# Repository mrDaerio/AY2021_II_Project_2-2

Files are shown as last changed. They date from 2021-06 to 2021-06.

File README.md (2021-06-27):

# Project 2 - Heart Rate Monitor Accelerometer
This repository contains all the files used to build a heart rate monitoring device, as requested by the final project of the course. The hardware used for this project consists in the CY8CKIT-059, a HC-05 Bluetooth module, a LIS3DH accelerometer and a breadbord which allows to connect all the components.

In this file are listed all the steps to reproduce and program the device, with also explanatory photos and images to help the user in the process.

## Device Building and Placement
In this first section is explained in detail how to build the device and where to place it on the body in order to obtain the best signal acquisition.

### Material:

As illustrated in the picture below, in order to reproduce the device is needed a microcontroller, a bluetooth module, an accelerometer (with the 3D printed case) and an elastic band to easily place it on the torax. The powerbank is not mandatory, but it is useful if the subject wants to have the possiblity to be physically detached from the computer.

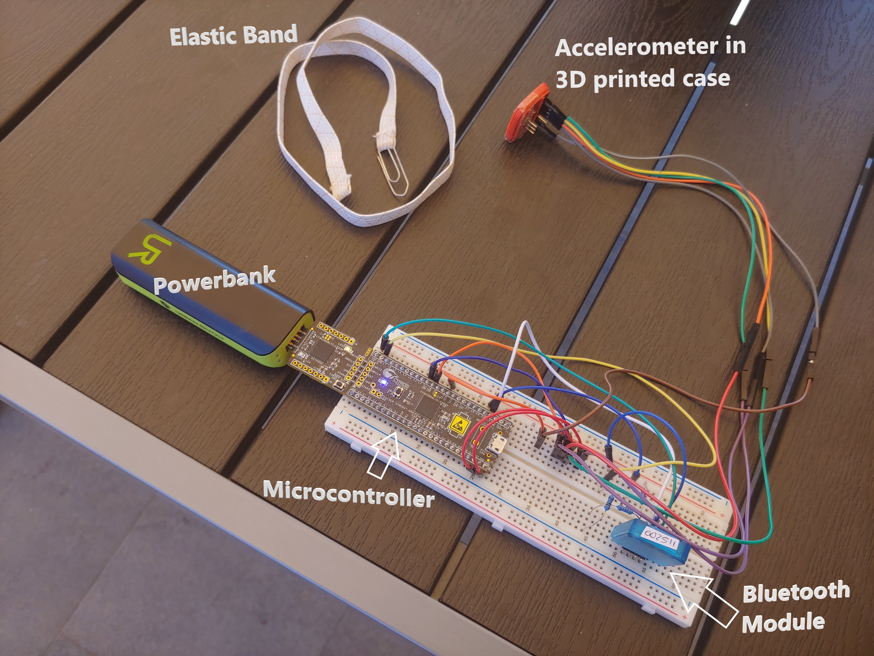
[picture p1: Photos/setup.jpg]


### Connection:

Follow the table below to properly connect the pins of the components to the microcontroller:

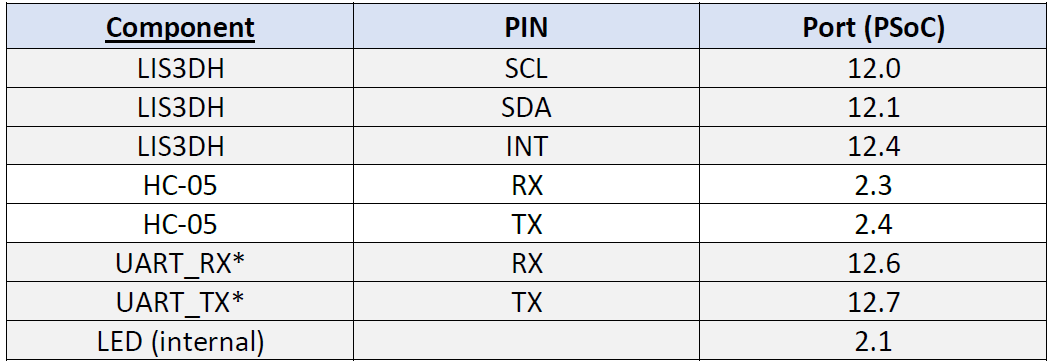
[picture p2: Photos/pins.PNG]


### 3D Case:

In order to have a better adeherence of the accelerometer to the body, and a better support for the elastic band, a special case has been developed, and it is possible to find all the relative information in the folder named "Case". 
The relative README file in the folder explains how to attach the case to the accelerometer.

### How to wear the sensor:

The rubber band needs to be placed behind the case, like showed in the picture below. 



A 3D animation shows how the accelerometer needs to be placed on the body, in order to obtain good acquisitions.



## Programming the Microcontroller

Once the repository has been downloaded on the computer, it's possible to program the kit through PSoC creator. To do that, simply double click on the file "Workspace01.cywrk",  and PSoC Creator will automatically open. Compile the project and upload it on the board. In the Top Design file is also possible to find other information and visual representation on how to connect the components to the board, if not clear.
Mind that a specific library has been used, called AnnotationLibrary. You might have to add it in order to correctly build the project and program the device.

If all the connection are correct, at the end of the programming phase you should have a red led blinking on the bluetooth module and the blue led of the microcontroller lighted up. If the blue led is blinking, it means that the accelerometer is not connected properly.

## GUI

The GUI has been developed with kivy, and allows to display the data retrieved by the microcontroller and elaborate them to extract the heart rate of the subject. Through the interface is possible also to have a graphical representation of the signal rielaborated, in order to have a clear representation of the beating, and also allows to change internal parameter of the microcontroller, such as the sample rate and the full scale range. Another feature is the data export of the three raw channels of the accelerometers in a .csv file, which can be used for further studies or further data elaboration on other platforms.
The microcontroller is also able to save the last parameter that the user has set, and retrieve them for the next session.

All the packets that need to be installed in the virtual environment to make the interface work are listed in the folder named "GUI". The bluetooth module connection with the computer can be established in the bluetooth settings, as any other bluetooth device. The module is called "HC-05", but the name may differ.

### First Run

Run the "main.py" file from a Python virtual environment to start the GUI. This window should appear:

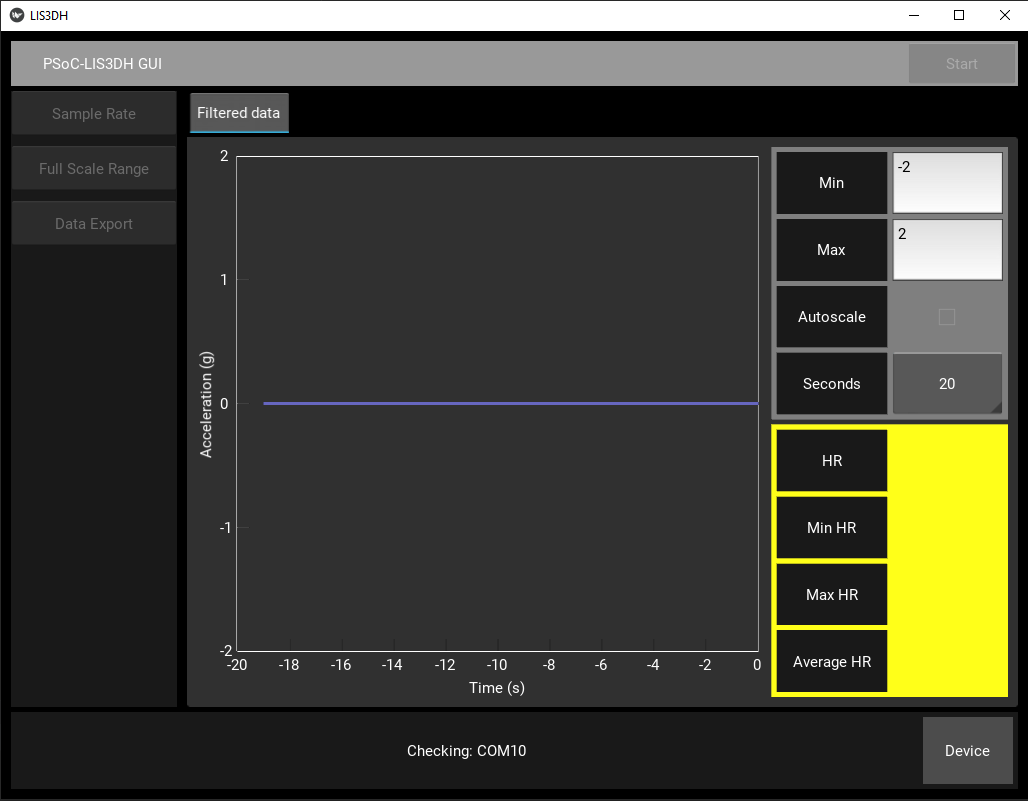
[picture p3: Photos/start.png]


### Connection

Once the connection with the bluetooth module has been established, the graphical interface should look like this:

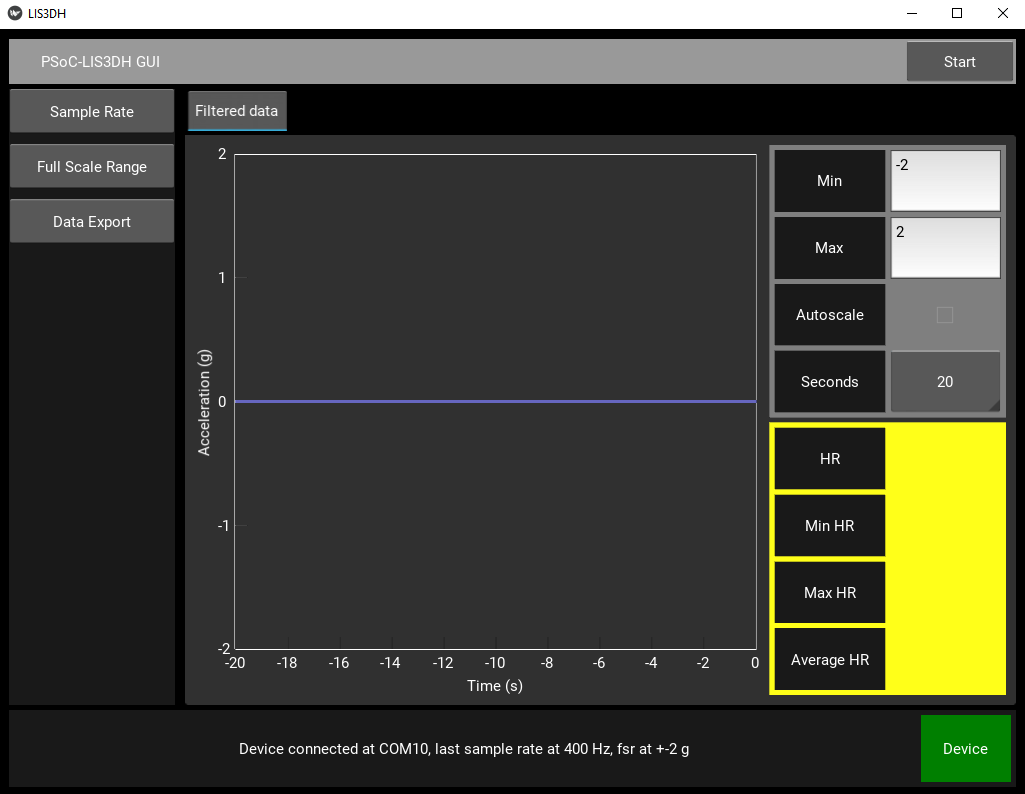
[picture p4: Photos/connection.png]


As it is possible to notice, the selection buttons can now be pressed to change the parameters of the microcontroller, and start button on the top right corner enables the data streaming and the graphical representation of the data.

The GUI should visualize the signal in this way:

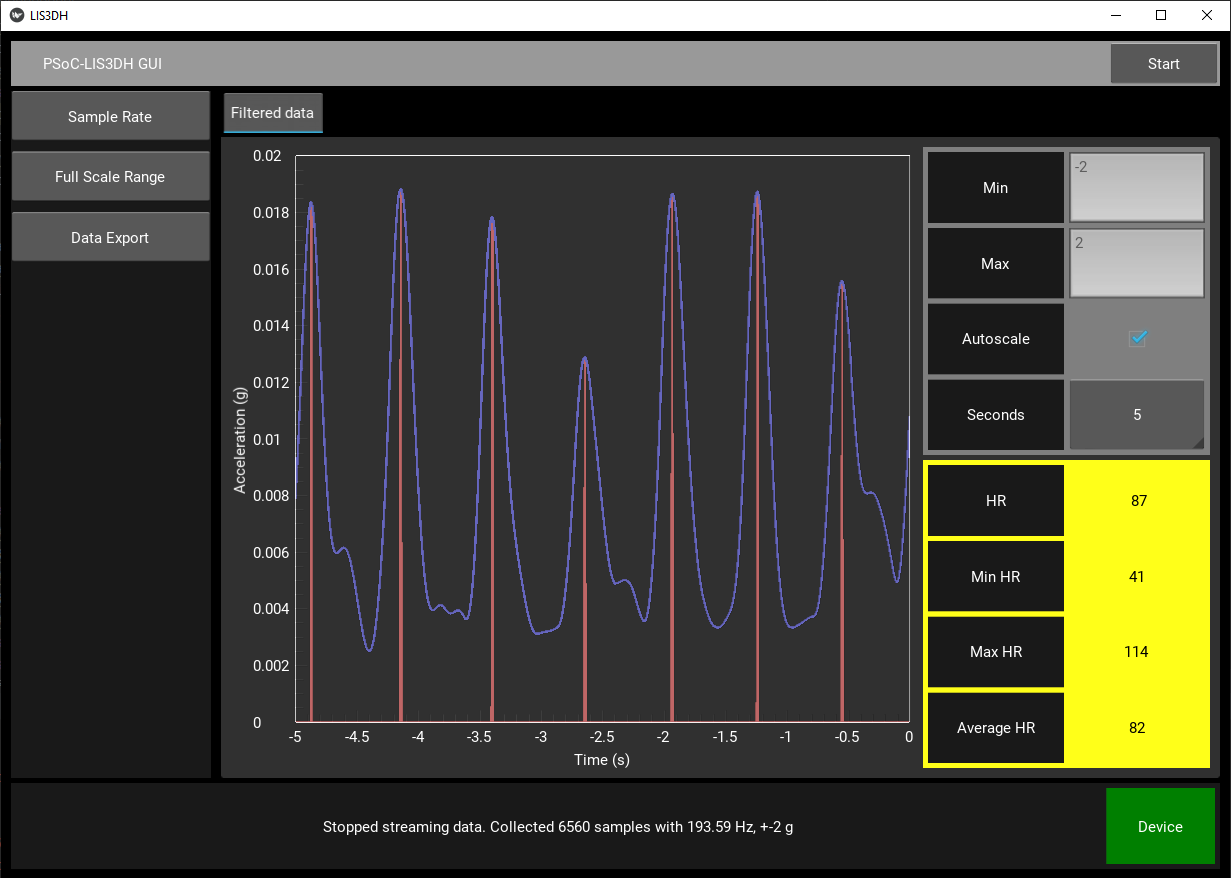
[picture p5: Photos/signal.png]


To interrput the connection, simply press the stop button. The data export button allows to save the current session locally in the computer.

Note that you have to wait about 10 seconds before seeing any plot on the GUI because vectors need to be filled and data needs to be processed.

The exported data saved in the csv file will contain all the data of the last acquisition (time between start and stop commands).

### How is the GUI structured?

Since the GUI code can be complicated at first glance, this graph tries to simplify and clarify every connection inside the code.
[Map of the GUI](https://miro.com/app/board/o9J_lDBEVHY=/)

## Students Authors of the Project

* Dario Comini

* Stefano Lucchesini

* Giovanni Merighi

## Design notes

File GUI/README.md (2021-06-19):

# LIS3DH GUI
This is a GUI showing how to read, parse, and plot acceleration data from a LIS3DH accelerometer.

## Requirements
- Kivy
- Kivy-Garden graph. To install it, run this command inside your virtual environment:
    - garden install graph
- PySerial
- SciPy
- numpy
- scikit-learn
- pandas

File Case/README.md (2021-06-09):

# Readme - HR monitor 3D Case
This folder contains the necessary files to 3D print a case for the LIS3DH accelerometer.
* The top part of the case ("Tappo") has two holes to let headers and wiring pass through <br/> and two small walls which are used to keep an elastic band in position.
* The bottom part ("Base") goes in contact with the skin and has two plastic pillars to keep the accelerometer board fixed.\
Base and Tappo can be glued together after the board is put inside.
* The .STEP file contains the 3D model, it can be opened in any 3D CAD app, we used FUSION 360.

| | |
|-|-|
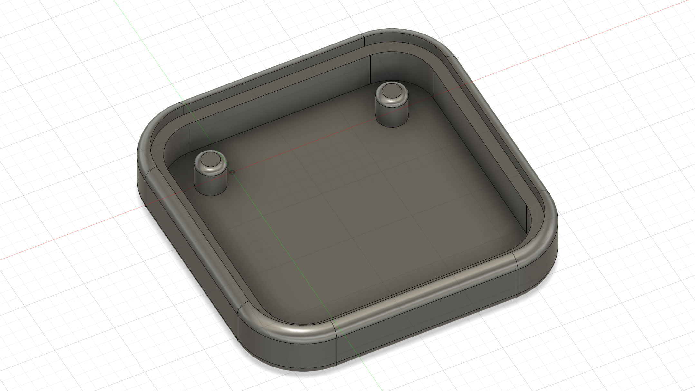
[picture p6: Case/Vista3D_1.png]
Vista_3D_1
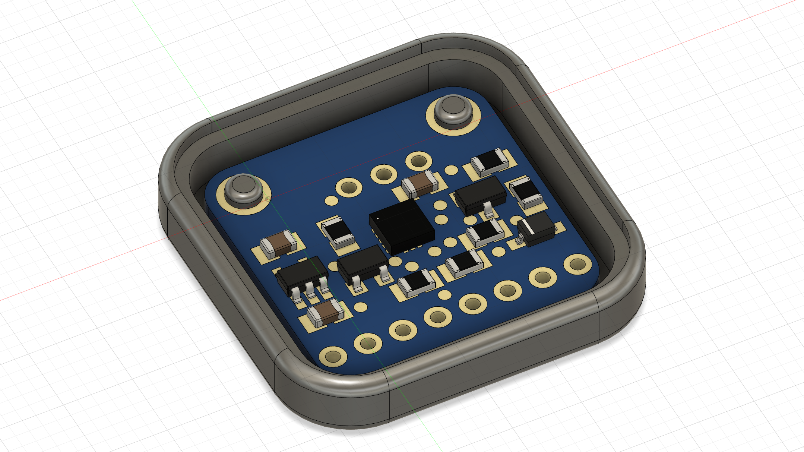
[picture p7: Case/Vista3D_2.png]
Vista_3D_2
|   |   |
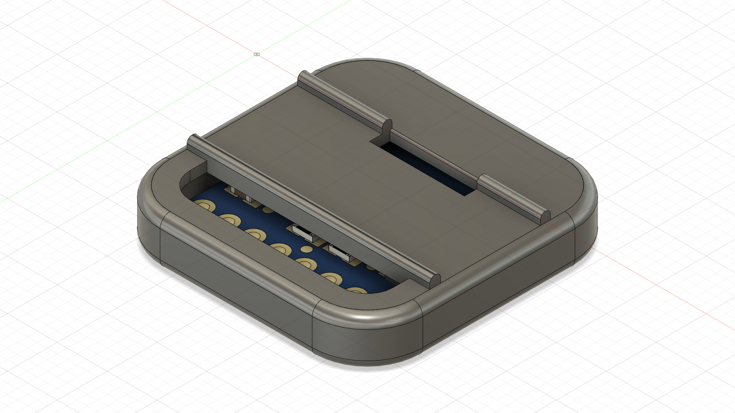
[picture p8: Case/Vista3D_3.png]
Vista_3D_3
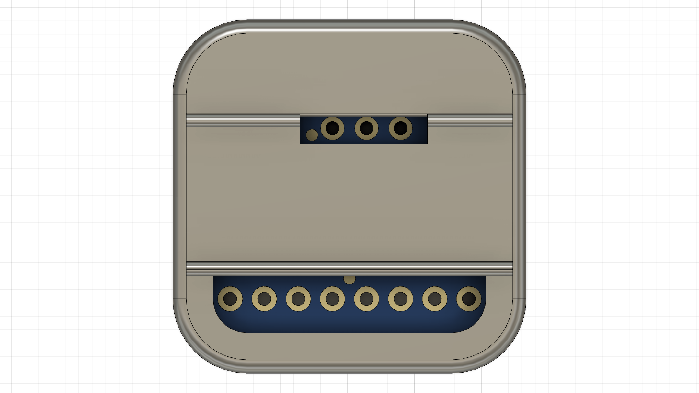
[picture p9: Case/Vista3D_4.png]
Vista_3D_4
|   |   |

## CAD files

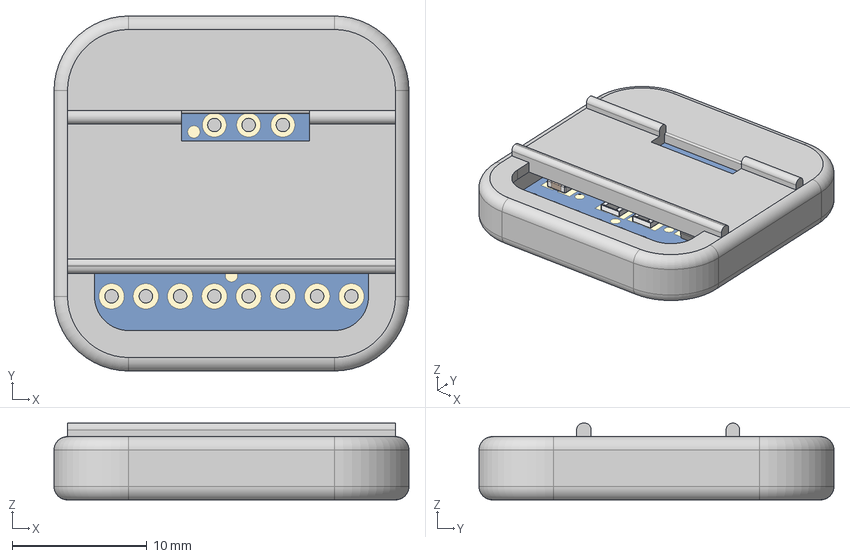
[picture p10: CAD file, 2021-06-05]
Case/HR Monitor Case.step
26.3 x 26.3 x 5.70 mm
SOT23-5 v1
SOT23-3 v1 x 2
16-LGA-3X3 v2
SMD Resistor 0805 v1 x 6
Cap 0805 v1 x 3
SOD-323 v1

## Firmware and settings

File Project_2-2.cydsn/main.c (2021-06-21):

/* =============================================================================
 
    Electronic Technologies and Biosensors Laboratory
    Academic Year 2020/2021 - II Semester
    Final Project
    GROUP_02 - Variant 2

    main.c: source file
 
 * =============================================================================
*/

#include "project.h"
#include "stdio.h"
#include "I2C_Interface.h"
#include "LIS3DH.h"
#include "ErrorCodes.h"
#include "InterruptRoutines.h"

// Definition of led value for blinking
#define LED_ON 99
#define LED_BLINK 50

// Definition of head and tail for data packets
#define HEAD 0xA0
#define TAIL 0xC0

// Definition of buffer size
#define BUFFER_SIZE 194

uint8_t flag = 0;
int16_t x_buffer[FIFO_SIZE], y_buffer[FIFO_SIZE], z_buffer[FIFO_SIZE];
uint8_t buffer[BUFFER_SIZE];

int main(void)
{
    CyGlobalIntEnable; /* Enable global interrupts. */
    
    // Start all components
    I2C_Peripheral_Start();
    UART_DEBUG_Start();
    UART_BT_Start();
    isr_FIFO_StartEx(Custom_ISR_FIFO);
    isr_BT_StartEx(Custom_ISR_RXBT);
    PWM_LED_Start();
    
    CyDelay(5); //"The boot procedure is complete about 5 ms after device power-up."
    
    if (!I2C_Peripheral_IsDeviceConnected(LIS3DH_DEVICE_ADDRESS))
        PWM_LED_WriteCompare(LED_BLINK);
    else
        PWM_LED_WriteCompare(LED_ON);
        
    CyDelay(10);
        
    // Accelerometer powered down
    ErrorCode error = set_datarate(LIS3DH_DATARATE_POWERDOWN);
    error_check(error);
    
    // Enables FIFO
    error = FIFO_set(1, FIFO_MODE);
    error_check(error);

    buffer[0] = HEAD;
    buffer[BUFFER_SIZE-1] = TAIL;
    
    for(;;)
    {      
        if(flag){
            flag = 0;
            for(int i=1; i <= FIFO_SIZE; i++) {
                    buffer[2*i - 1] = x_buffer[i-1] >> 8;
                    buffer[2*i] = x_buffer[i-1];
                    buffer[2*i + 2*FIFO_SIZE - 1] = y_buffer[i-1] >> 8;
                    buffer[2*i + 2*FIFO_SIZE] = y_buffer[i-1];
                    buffer[2*(i + 2*FIFO_SIZE) - 1] = z_buffer[i-1] >> 8;
                    buffer[2*(i + 2*FIFO_SIZE)] = z_buffer[i-1];
            }
            UART_BT_PutArray(buffer, BUFFER_SIZE);
        }    
    }
}

/* [] END OF FILE */

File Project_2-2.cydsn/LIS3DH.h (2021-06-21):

/* =============================================================================
 
    Electronic Technologies and Biosensors Laboratory
    Academic Year 2020/2021 - II Semester
    Final Project
    GROUP_02 - Variant 2

    LIS3DH.h: header file 

    This is a library for the Adafruit LIS3DH Accel breakout board
    Designed specifically to work with the Adafruit LIS3DH Triple-Axis
    Accelerometer
    (+-2g/4g/8g/16g)
    This sensor communicates over I2C or SPI (our library code supports
    both) so you can share it with a bunch of other sensors on the same I2C bus.
    There's an address selection pin so you can have two accelerometers share an
    I2C bus.
    
    Adafruit invests time and resources providing this open source code,
    please support Adafruit andopen-source hardware by purchasing products
    from Adafruit!
 
 * =============================================================================
*/

#include "cytypes.h"
#include "ErrorCodes.h"
#include "I2C_Interface.h"

#ifndef __LIS3DH_H
    #define __LIS3DH_H
    
    // Definition of the size of the FIFO
    #define FIFO_SIZE 32
    
    /** I2C ADDRESS/BITS **/
    #define LIS3DH_DEVICE_ADDRESS (0x18) // if SDO/SA0 is 3V, its 0x19

    /*!
     *  STATUS_REG_AUX register
     *   321OR  1, 2 and 3 axis data overrun. Default value: 0
     *          (0: no overrun has occurred; 1: a new set of data has overwritten
     *  the previous ones) 3OR    3 axis data overrun. Default value: 0 (0: no
     *  overrun has occurred; 1: a new data for the 3-axis has overwritten the
     *  previous one) 2OR    2 axis data overrun. Default value: 0 (0: no overrun has
     *  occurred; 1: a new data for the 4-axis has overwritten the previous one) 1OR
     *  1 axis data overrun. Default value: 0 (0: no overrun has occurred; 1: a new
     *  data for the 1-axis has overwritten the previous one) 321DA  1, 2 and 3 axis
     *  new data available. Default value: 0 (0: a new set of data is not yet
     *  available; 1: a new set of data is available) 3DA:   3 axis new data
     *  available. Default value: 0 (0: a new data for the 3-axis is not yet
     *  available; 1: a new data for the 3-axis is available) 2DA:   2 axis new data
     *  available. Default value: 0 (0: a new data for the 2-axis is not yet
     *  available; 1: a new data for the 2-axis is available) 1DA    1 axis new data
     *  available. Default value: 0 (0: a new data for the 1-axis is not yet
     *  available; 1: a new data for the 1-axis is available)
     */
    #define LIS3DH_REG_STATUS1 0x07
    
    #define LIS3DH_REG_OUTADC1_L 0x08 /**< 1-axis acceleration data. Low value */
    #define LIS3DH_REG_OUTADC1_H 0x09 /**< 1-axis acceleration data. High value */
    #define LIS3DH_REG_OUTADC2_L 0x0A /**< 2-axis acceleration data. Low value */
    #define LIS3DH_REG_OUTADC2_H 0x0B /**< 2-axis acceleration data. High value */
    #define LIS3DH_REG_OUTADC3_L 0x0C /**< 3-axis acceleration data. Low value */
    #define LIS3DH_REG_OUTADC3_H 0x0D /**< 3-axis acceleration data. High value */
    
    #define LIS3DH_REG_INTCOUNT                                                    \
      0x0E /**< INT_COUNTER register [IC7, IC6, IC5, IC4, IC3, IC2, IC1, IC0] */
    
    #define LIS3DH_REG_WHOAMI                                                      \
      0x0F /**< Device identification register. [0, 0, 1, 1, 0, 0, 1, 1] */
    #define LIS3DH_WHOAMI_RETVAL 0x33  // WHO AM I register return value
    
    #define LIS3DH_NORMAL_MODE_OFF_CTRL_REG1 0x07  // Hex value to set normal mode (powered off)
    
    /*!
     *  TEMP_CFG_REG
     *  Temperature configuration register.
     *   ADC_PD   ADC enable. Default value: 0
     *            (0: ADC disabled; 1: ADC enabled)
     *   TEMP_EN  Temperature sensor (T) enable. Default value: 0
     *            (0: T disabled; 1: T enabled)
     */
    #define LIS3DH_REG_TEMPCFG 0x1F
    
    #define LIS3DH_TEMP_CFG_REG_ACTIVE 0xC0
    
    #define LIS3DH_CTRL_REG0 0x1E
    
    /*!
     *  CTRL_REG1
     *  [ODR3, ODR2, ODR1, ODR0, LPen, Zen, Yen, Xen]
     *   ODR3-0  Data rate selection. Default value: 00
     *           (0000:50 Hz; Others: Refer to Datasheet Table 26, “Data rate
     * configuration”) LPen    Low power mode enable. Default value: 0 (0: normal
     * mode, 1: low power mode) Zen     Z axis enable. Default value: 1 (0: Z axis
     * disabled; 1: Z axis enabled) Yen     Y axis enable. Default value: 1 (0: Y
     * axis disabled; 1: Y axis enabled) Xen     X axis enable. Default value: 1 (0:
     * X axis disabled; 1: X axis enabled)
     */
    #define LIS3DH_REG_CTRL1 0x20
    
    /*!
     *  CTRL_REG2
     *  [HPM1, HPM0, HPCF2, HPCF1, FDS, HPCLICK, HPIS2, HPIS1]
     *   HPM1-0  High pass filter mode selection. Default value: 00
     *           Refer to Table 29, "High pass filter mode configuration"
     *   HPCF2-1 High pass filter cut off frequency selection
     *   FDS     Filtered data selection. Default value: 0
     *					 (0: internal filter bypassed; 1: data
     *from internal filter sent to output register and FIFO) HPCLICK High pass
     *filter enabled for CLICK function. (0: filter bypassed; 1: filter enabled)
     *HPIS2   X axis enable. Default value: 1 (0: X axis disabled; 1: X axis
     *enabled) HPIS1 High pass filter enabled for AOI function on interrupt 1, (0:
     *filter bypassed; 1: filter enabled)
     */
    
    #define LIS3DH_REG_CTRL1_DATA_RATE_BITS_MASK 0b11110000
    #define LIS3DH_REG_CTRL1_RANGE_BITS_MASK 0b00110000
    #define LIS3DH_REG_CTRL5_FIFO_SET_BITS_MASK 0b01000000
    #define LIS3DH_REG_FIFOCTRL_FIFO_MODE_BITS_MASK 0b11000000
    #define LIS3DH_REG_CTRL3_FIFO_INT1_BITS_MASK 0b00000010
    
    
    
    #define LIS3DH_REG_CTRL2 0x21
    
    /*!
     *  CTRL_REG3
     *  [I1_CLICK, I1_AOI1, I1_AOI2, I1_DRDY1, I1_DRDY2, I1_WTM, I1_OVERRUN, --]
     *   I1_CLICK    CLICK interrupt on INT1. Default value 0.
     *						   (0: Disable; 1: Enable)
     *   I1_AOI1     AOI1 interrupt on INT1. Default value 0.
     *						   (0: Disable; 1: Enable)
     *   I1_AOI2     AOI2 interrupt on INT1. Default value 0.
     *               (0: Disable; 1: Enable)
     *   I1_DRDY1    DRDY1 interrupt on INT1. Default value 0.
     *               (0: Disable; 1: Enable)
     *   I1_DRDY2    DRDY2 interrupt on INT1. Default value 0.
     *               (0: Disable; 1: Enable)
     *   I1_WTM      FIFO Watermark interrupt on INT1. Default value 0.
     *               (0: Disable; 1: Enable)
     *   I1_OVERRUN  FIFO Overrun interrupt on INT1. Default value 0.
     * 							 (0: Disable; 1: Enable)
     */
    #define LIS3DH_REG_CTRL3 0x22
    
    /*!
     *  CTRL_REG4
     *  [BDU, BLE, FS1, FS0, HR, ST1, ST0, SIM]
     *   BDU      Block data update. Default value: 0
     *            (0: continuos update; 1: output registers not updated until MSB
     * and LSB reading) BLE      Big/little endian data selection. Default value 0.
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

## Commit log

2021-05-07 successfully read accelerometer X-axis LSB
2021-05-07 LSB and MSB read x-axis
2021-05-08 Error handling and functions to read and write registers
    [ErrorCodes.c, LIS3DH.h, main.c]
2021-05-08 Added datarate set function, FIFO set function, readout of all axes. Interrupt pin in topdesign
2021-05-09 Every function has its own error code, useful to quickly see (via UART) if there's any problem with the code
    [ErrorCodes.c, I2C_Interface.c, main.c]
2021-05-10 FIFO read with interrupt handling
2021-05-10 LED handling and macros for CTRL_REG bits
2021-05-11 simplified functions with set_reg_masked_only, macros for LED state, corrected ';' in some macros
    [LIS3DH.h, main.c]
2021-05-15 Added 400Hz and 1344Hz in gui
2021-05-15 Modified the variation in the interrupt of the sample rate, but the GUI doesn't work the after the second change
2021-05-17 Renamed values to avoid hard coding
    [main.c]
2021-05-17 Corrected typo in buffer handling
    [main.c]
2021-05-22 Band pass filtering of z+x signal using SciPy and plot in GUI in place of y
2021-05-22 sliding window for filter, first attempt for envelope
2021-05-26 Corrected sample_rate and used it for bpm calculation
    [communication.py]
2021-05-29 Removed frequencies below 100Hz, set 200Hz as default, disabled range select button
2021-05-29 Added filtered graph tab, only one tab working at a time because of high latency, corrected autoscale problem
    [communication.py, graph_tabs.py]
2021-06-02 FIFO read using ReadRegisterMulti function, sample rate now goes closer to the target one
2021-06-05 Added 3D case files
    [HR Monitor Case.step]
2021-06-05 Added miracolous fix with lowpass filter and corrected y_min autoscale
    [communication.py, graph_tabs.py]
2021-06-09 3D case images in README.md
2021-06-15 code organization in filtering part
2021-06-15 adaptive filtering of envelope, relative prominence, simplified logic peaks
2021-06-15 added min and max bpm visualization, prevented autoscale to cut the top of peaks
    [graph_tabs.py]
2021-06-19 Disable the GUI in case of I2C error, shorter window size
    [communication.py, main.py]
2021-06-19 Enter in an infinite loop and send error message in case o I2C disconnection
    [ErrorCodes.c, I2C_Interface.c, main.c]
2021-06-21 Removed from GUI graph the z-axis that wasn't used
2021-06-22 Corrected typo in topdesign and bluetooth module connected to uart
2021-06-22 Possibility to choose 400Hz sample rate
2021-06-22 README upper case PNG
2021-06-25 Added some comments and corrected nyquist calculation and reset
    [communication.py, main.py]
2021-06-27 Added mean bpm on gui, peak search depending on sample rate, new photos of GUI
